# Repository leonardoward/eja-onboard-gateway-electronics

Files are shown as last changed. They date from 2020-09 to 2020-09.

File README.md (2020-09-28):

# EJA Onboard Gateway - Electronic Design

EJA Onboard Gateway - Electronic Design - [2020 Hackaday Dream Team Challenge for Conservation X Labs](https://hackaday.io/project/173457-2020-hdp-dream-team-conservation-x-labs)

Onboard Gateway is a 134.11 mm x 62.48 mm PCB that integrates the 3 main components (ESP32, LoRa and USB LiIon/LiPoly charger)

This repository contains the KiCad design for the PCB of the Onboard Gateway. It also contains the 3D models used to visualize the design in the KiCad 3D viewer.

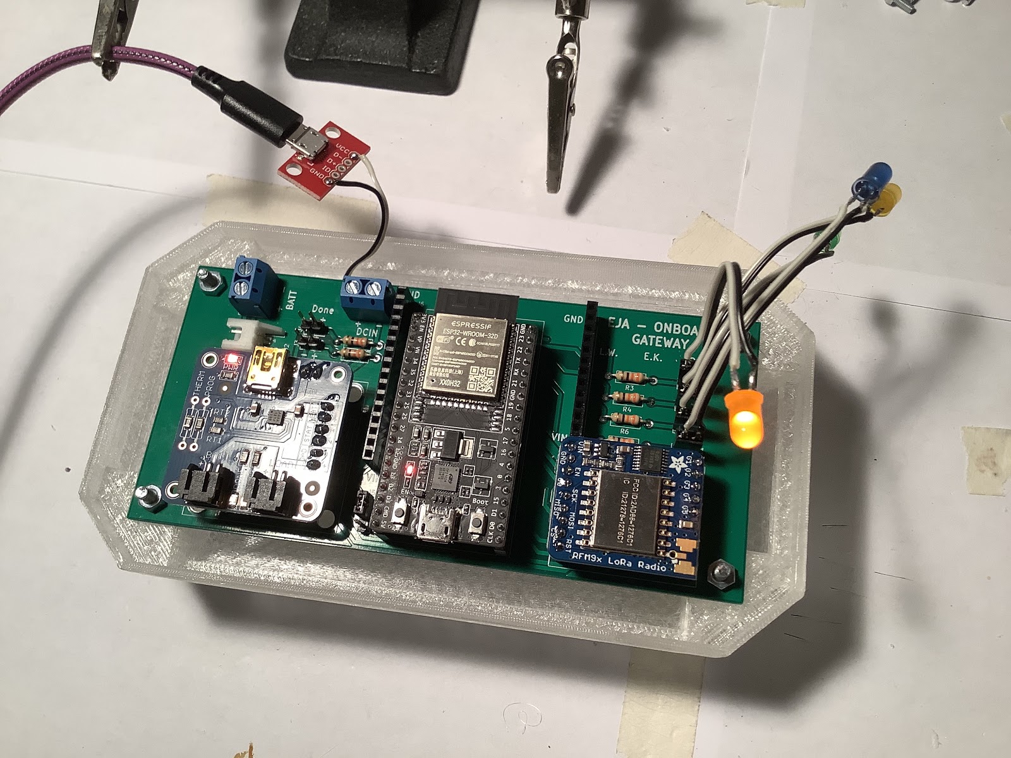
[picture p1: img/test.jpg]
Onboard Gateway


## Main Components ##

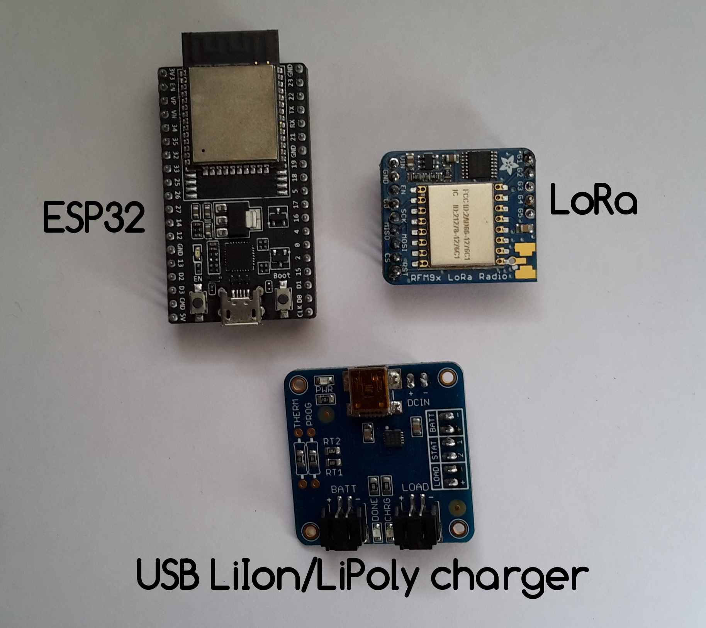
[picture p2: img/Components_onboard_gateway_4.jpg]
Components


Sources:

- [ESP32-DEVKITC-32D](https://www.digikey.com/product-detail/es/espressif-systems/ESP32-DEVKITC-32D/1965-1000-ND/9356990)
- [RFM95W LoRa Radio](https://www.digikey.com/product-detail/es/adafruit-industries-llc/3072/1528-1667-ND/6005357)
- [USB LiIon/LiPoly charger](https://www.adafruit.com/product/259)

## Schematic ##

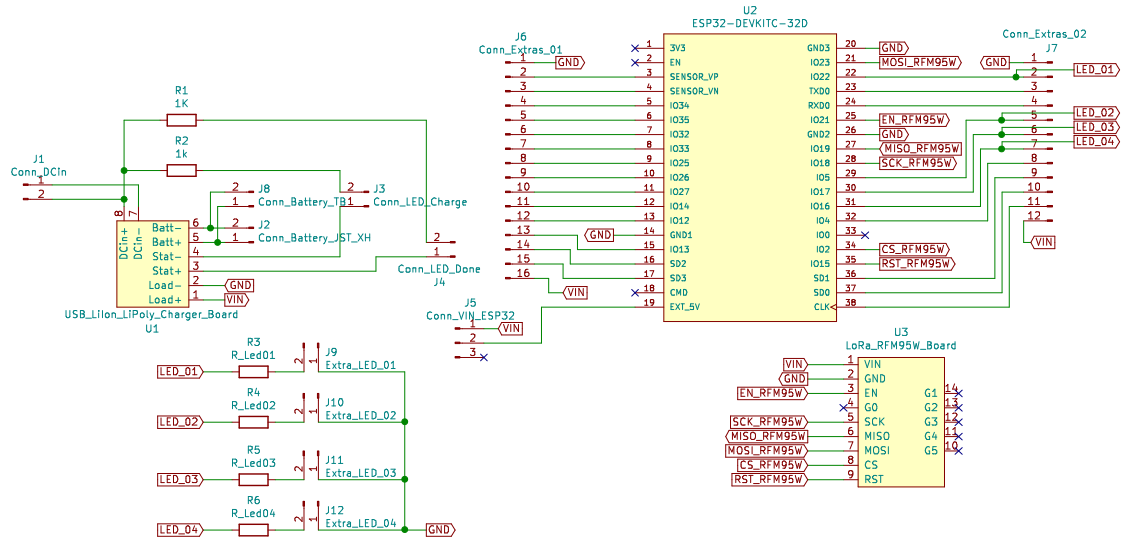
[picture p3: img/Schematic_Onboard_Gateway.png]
Schematic


[For a detailed explanation of the schematic visit the following log.](https://hackaday.io/project/173457/log/181839-onboard-gateway-v10-schematic-and-pcb-design)

## PCB Layout ##

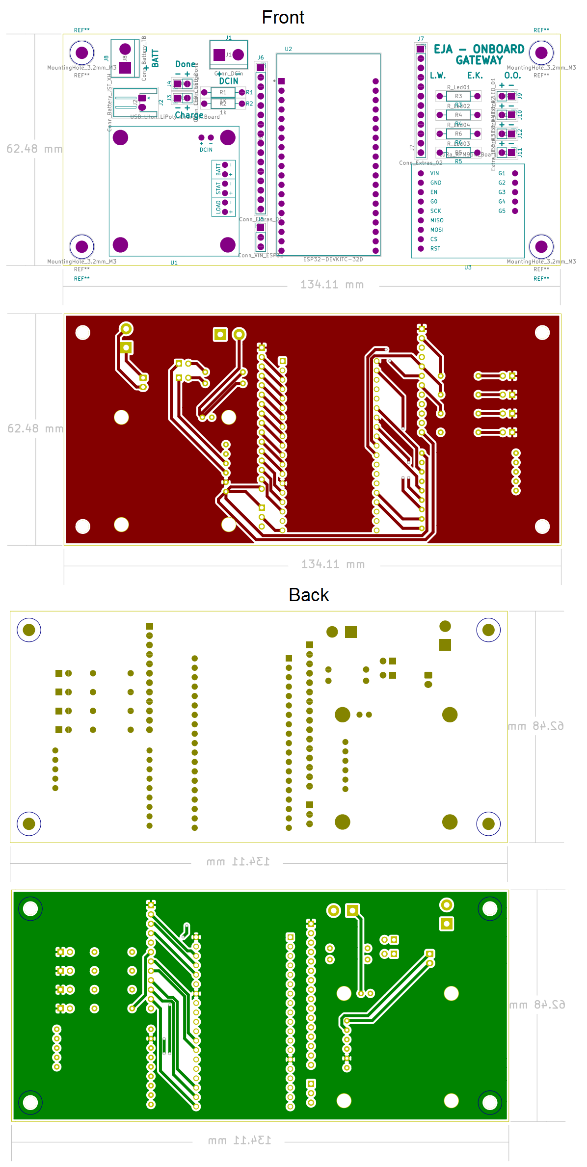
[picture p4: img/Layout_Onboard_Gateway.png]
PCB Layout


## Assembly ##

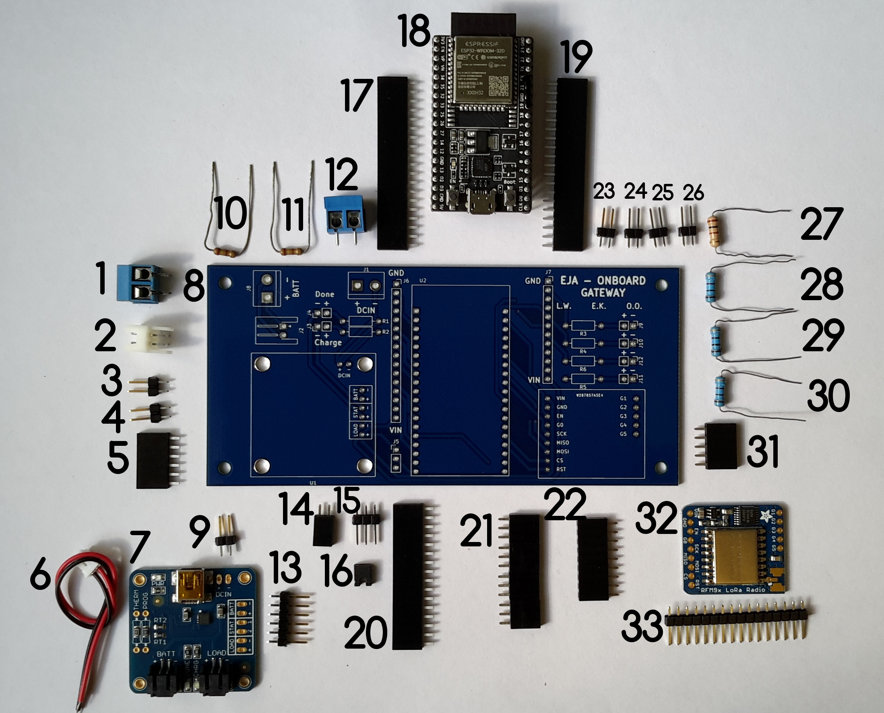
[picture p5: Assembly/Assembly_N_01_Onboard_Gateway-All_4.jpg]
Assembly Guide


Components List:

1. [TERM BLK 2P SIDE ENT 5.08MM PCB](https://www.digikey.com/product-detail/es/on-shore-technology-inc/OSTTC022162/ED2609-ND/614558)
2. [CONN HEADER R/A 2POS 2.5MM](https://www.digikey.com/product-detail/es/jst-sales-america-inc/S2B-XH-A-1-LF-SN/455-4226-ND/9961922)
3. [CONN HEADER VERT 2POS 2.54MM](https://www.digikey.com/product-detail/es/3m/2340-6111TG/3M11928-ND/1237275)
4. [CONN HEADER VERT 2POS 2.54MM](https://www.digikey.com/product-detail/es/3m/2340-6111TG/3M11928-ND/1237275)
5. [CONN HDR 6POS 0.1 TIN PCB](https://www.digikey.com/product-detail/es/sullins-connector-solutions/PPTC061LFBN-RC/S7004-ND/810145)
6. 2POS JST cable (included in the [USB LiIon/LiPoly charger](https://www.adafruit.com/product/259))
7. [USB LiIon/LiPoly charger](https://www.adafruit.com/product/259)
8. Onboard Gateway V1.0
9. [CONN HEADER VERT 2POS 2.54MM](https://www.digikey.com/product-detail/es/3m/2340-6111TG/3M11928-ND/1237275)
10. [RES 249 OHM 1/4W 1% AXIAL](https://www.digikey.com/product-detail/en/stackpole-electronics-inc/RNF14FTD249R/RNF14FTD249RCT-ND/1974990)
11. [RES 249 OHM 1/4W 1% AXIAL](https://www.digikey.com/product-detail/en/stackpole-electronics-inc/RNF14FTD249R/RNF14FTD249RCT-ND/1974990)
12. [TERM BLK 2P SIDE ENT 5.08MM PCB](https://www.digikey.com/product-detail/es/on-shore-technology-inc/OSTTC022162/ED2609-ND/614558)
13. [CONN HEADER VERT 6POS 2.54MM](https://www.digikey.com/product-detail/es/3m/2340-6111TG/3M11928-ND/1237275)
14. [CONN HDR 2POS 0.1 GOLD PCB](https://www.digikey.com/product-detail/es/sullins-connector-solutions/PPPC021LFBN-RC/S7035-ND/810174)
15. [CONN HEADER VERT 3POS 2.54MM](https://www.digikey.com/product-detail/es/3m/2340-6111TG/3M11928-ND/1237275)
16. [CONN JUMPER SHORTING .100" GOLD](https://www.digikey.com/product-detail/es/sullins-connector-solutions/QPC02SXGN-RC/S9337-ND/2618262)
17. [CONN HDR 19POS 0.1 TIN PCB](https://www.digikey.com/product-detail/es/sullins-connector-solutions/PPTC191LFBN-RC/S7017-ND/810157)
18. [ESP32-DEVKITC-32D](https://www.digikey.com/product-detail/es/espressif-systems/ESP32-DEVKITC-32D/1965-1000-ND/9356990)
19. [CONN HDR 19POS 0.1 TIN PCB](https://www.digikey.com/product-detail/es/sullins-connector-solutions/PPTC191LFBN-RC/S7017-ND/810157)
20. [CONN HDR 16POS 0.1 TIN PCB](https://www.digikey.com/product-detail/es/sullins-connector-solutions/PPTC161LFBN-RC/S7014-ND/810154)
21. [CONN HDR 12POS 0.1 TIN PCB](https://www.digikey.com/product-detail/es/sullins-connector-solutions/PPTC121LFBN-RC/S6100-ND/807231) (I used 2 [CONN HDR 6POS 0.1 TIN PCB](https://www.digikey.com/product-detail/es/sullins-connector-solutions/PPTC061LFBN-RC/S7004-ND/810145) in the image)
22. [CONN HDR 9POS 0.1 GOLD PCB](https://www.digikey.com/product-detail/es/sullins-connector-solutions/PPPC091LFBN-RC/S7042-ND/810181)
23. [CONN HEADER VERT 2POS 2.54MM](https://www.digikey.com/product-detail/es/3m/2340-6111TG/3M11928-ND/1237275)
24. [CONN HEADER VERT 2POS 2.54MM](https://www.digikey.com/product-detail/es/3m/2340-6111TG/3M11928-ND/1237275)
25. [CONN HEADER VERT 2POS 2.54MM](https://www.digikey.com/product-detail/es/3m/2340-6111TG/3M11928-ND/1237275)
26. [CONN HEADER VERT 2POS 2.54MM](https://www.digikey.com/product-detail/es/3m/2340-6111TG/3M11928-ND/1237275)
27. [RES 100 OHM 3W 5% AXIAL](https://www.digikey.com/product-detail/en/vishay-beyschlag-draloric-bc-components/AC03000001000JAC00/PPC3W100CT-ND/596604)
28. [RES 100 OHM 3W 5% AXIAL](https://www.digikey.com/product-detail/en/vishay-beyschlag-draloric-bc-components/AC03000001000JAC00/PPC3W100CT-ND/596604)
29. [RES 100 OHM 3W 5% AXIAL](https://www.digikey.com/product-detail/en/vishay-beyschlag-draloric-bc-components/AC03000001000JAC00/PPC3W100CT-ND/596604)
30. [RES 100 OHM 3W 5% AXIAL](https://www.digikey.com/product-detail/en/vishay-beyschlag-draloric-bc-components/AC03000001000JAC00/PPC3W100CT-ND/596604)
31. [CONN HDR 5POS 0.1 GOLD PCB](https://www.digikey.com/product-detail/es/sullins-connector-solutions/PPTC051LFBN-RC/S6103-ND/807239)
32. [RFM95W LoRa Radio](https://www.digikey.com/product-detail/es/adafruit-industries-llc/3072/1528-1667-ND/6005357)
33. CONN HEADER VERT 16POS 2.54MM (included in [RFM95W LoRa Radio](https://www.digikey.com/product-detail/es/adafruit-industries-llc/3072/1528-1667-ND/6005357))

[For a detailed Bill of Materials visit the following log.](https://hackaday.io/project/173457/log/183759-onboard-gateway-v10-bill-of-materials)

[For a detailed explanation about the soldering and assembly procedure visit the following log.](https://hackaday.io/project/173457/log/183665-onboard-gateway-v10-assembly)

## Wiring Diagrams ##

The following diagram presents the physical connections of the different boards and components of the Onboard Gateway, that includes:

- 3.7V 1 Cell Battery
- Leds (Charge, Done and 4 Miscellaneous)
- PCB Board for the Onboard Gateway V1.0
- 5V Charger (only used to charge the battery)
- Micro USB Breakout Board
- Switch

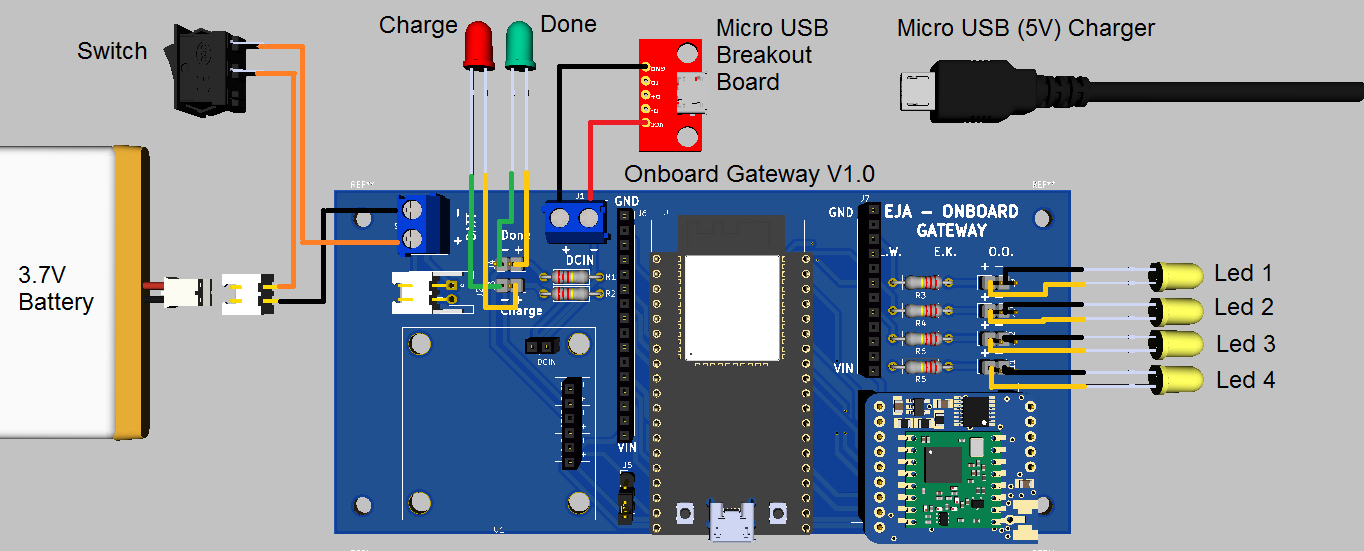
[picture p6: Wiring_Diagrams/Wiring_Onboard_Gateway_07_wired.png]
Wiring Diagrams


[For more information about the wiring diagrams and the project visit the following log.](https://hackaday.io/project/173457-2020-hdp-dream-team-conservation-x-labs/log/182586-onboard-gateway-v10-wiring-diagram)

## Future improvements ##

[For more information about the recommended future improvements for the electronic design visit the following log.](https://hackaday.io/project/173457/log/183807-future-improvements-pcb-design)

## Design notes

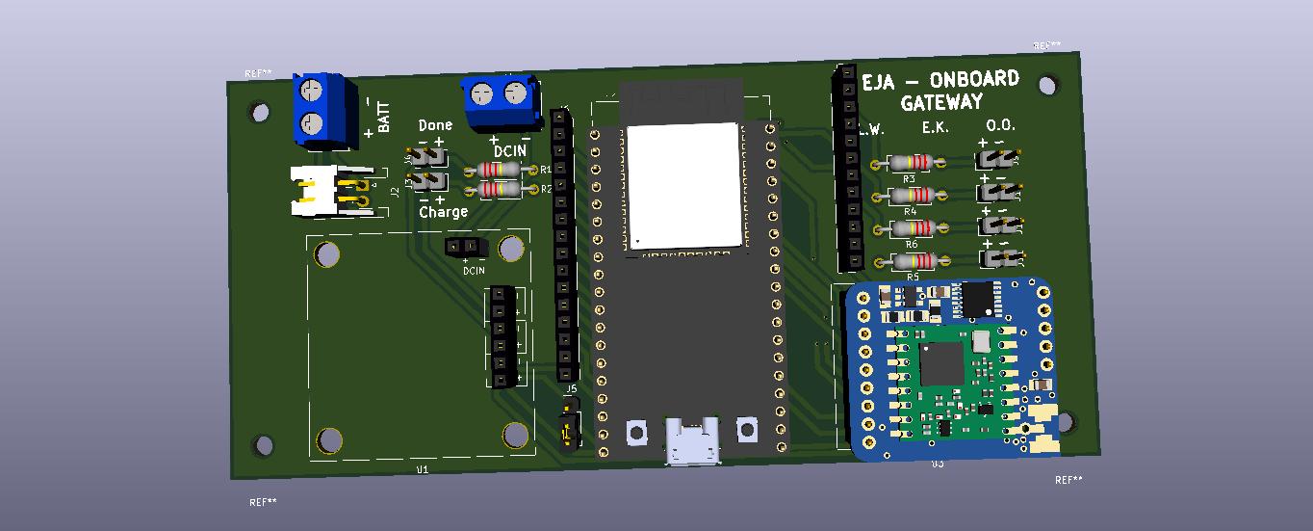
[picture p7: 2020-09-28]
img/Onboard_Gateway_V1.0_01.jpg

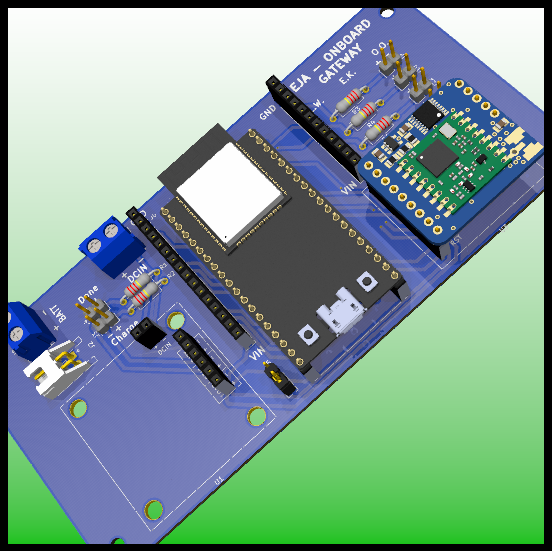
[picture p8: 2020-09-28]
img/Onboard Gateway V1.0 02.png

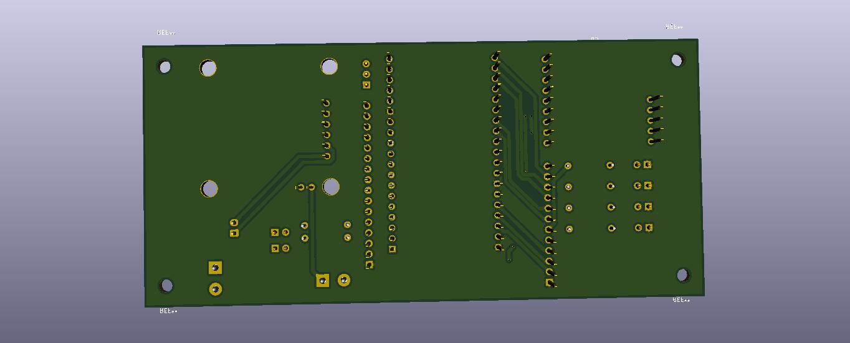
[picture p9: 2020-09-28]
img/Onboard_Gateway_V1.0_02.jpg

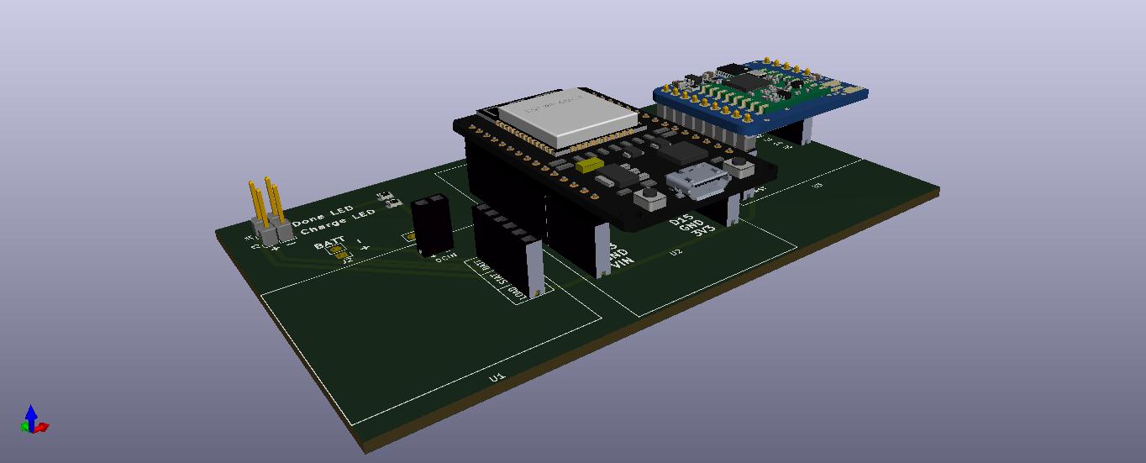
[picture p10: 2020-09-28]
img/Onboard_Gateway_02.jpg

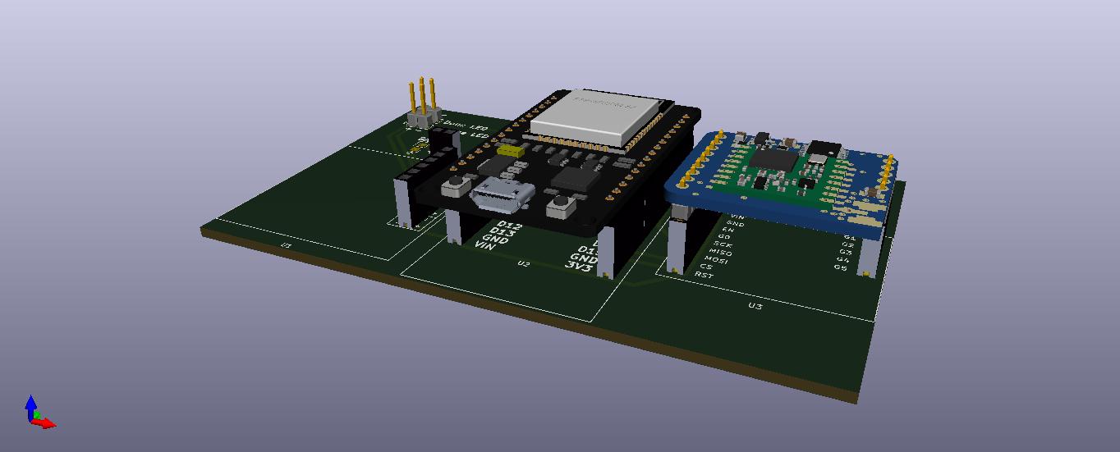
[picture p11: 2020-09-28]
img/Onboard_Gateway_03.jpg

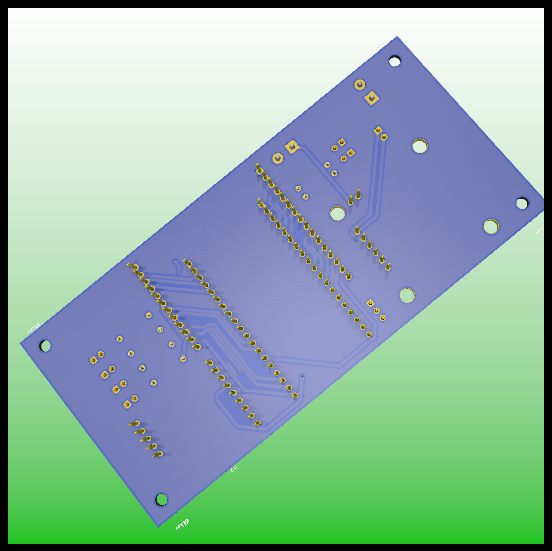
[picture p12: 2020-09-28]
img/Onboard Gateway V1.0 06.png

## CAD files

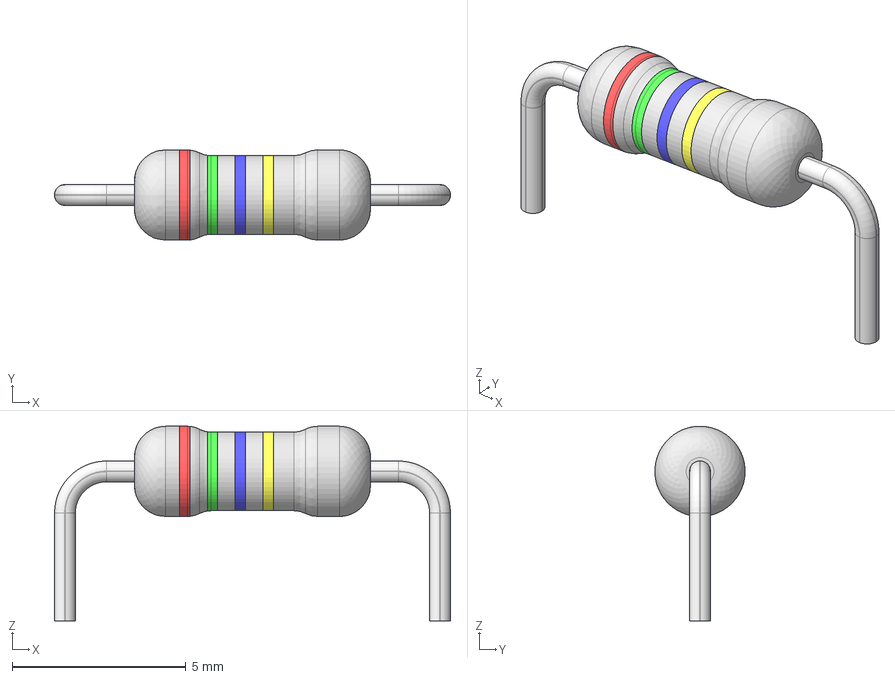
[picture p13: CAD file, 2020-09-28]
3D/axial_resistor_L6.8_D2.6_PinD0.6_Pitch10.8_gray.step
11.4 x 2.60 x 5.60 mm

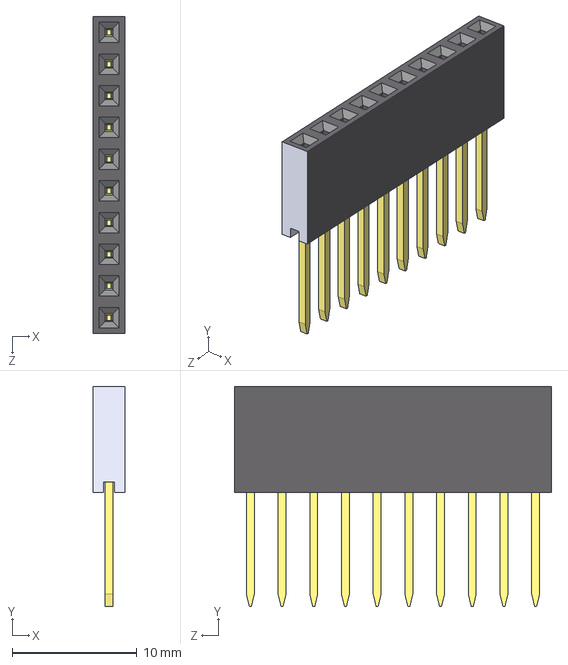
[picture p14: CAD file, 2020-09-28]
3D/Female Header 1x10.STEP
2.54 x 17.6 x 25.4 mm

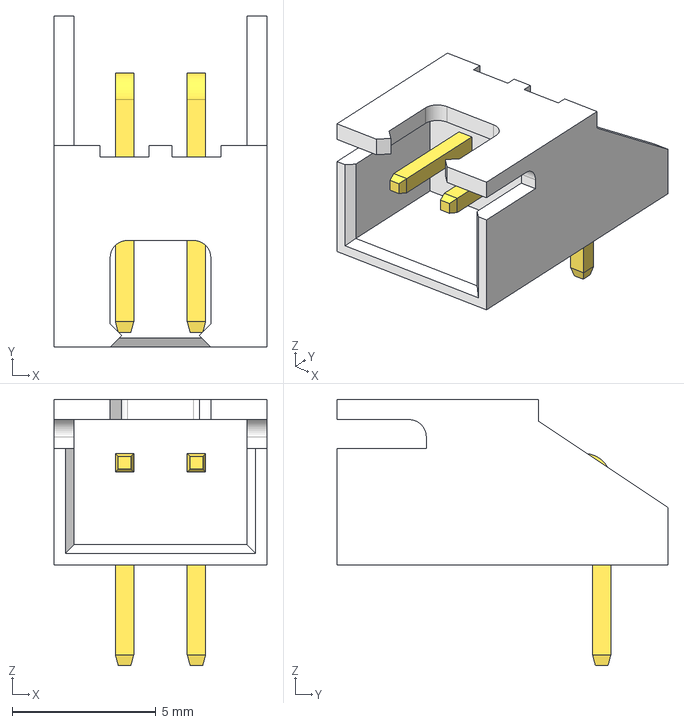
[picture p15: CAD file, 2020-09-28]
3D/S2B-XH-A.step
7.40 x 11.5 x 9.25 mm

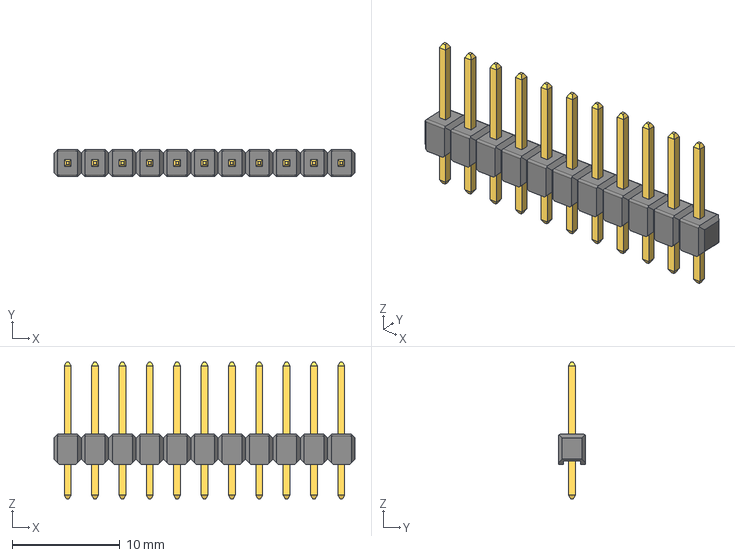
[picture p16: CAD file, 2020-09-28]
3D/Pin Header 1x11 TH Pitch 2.54mm.stp
27.9 x 2.54 x 12.7 mm

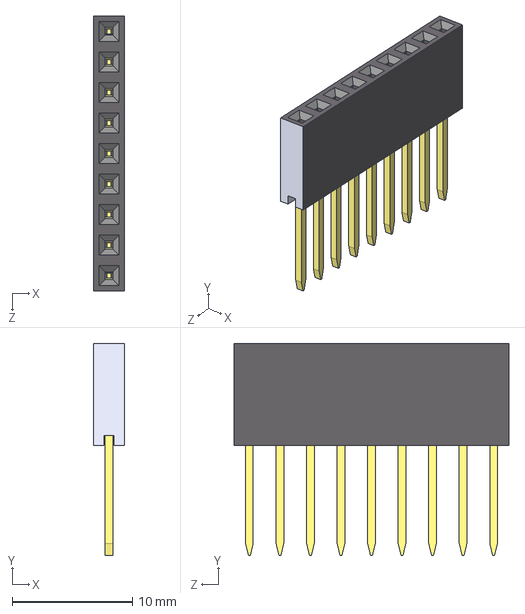
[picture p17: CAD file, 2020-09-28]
3D/Female Header 1x9.STEP
2.54 x 17.6 x 22.9 mm

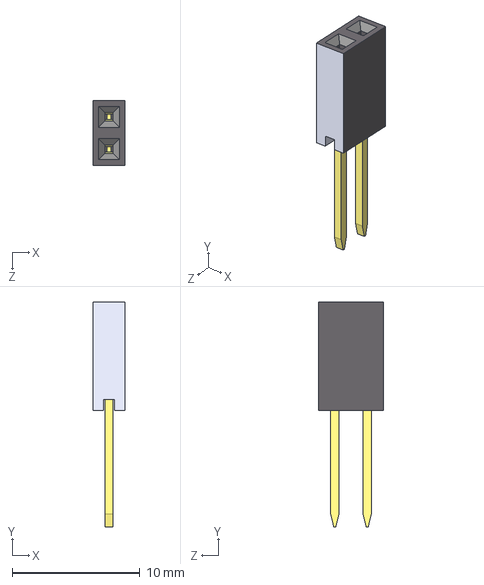
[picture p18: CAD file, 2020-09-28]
3D/Female Header 1x2.STEP
2.54 x 17.6 x 5.08 mm

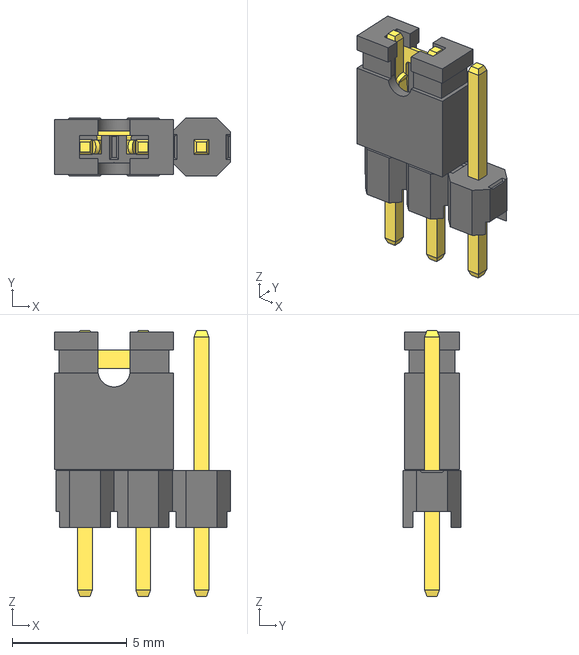
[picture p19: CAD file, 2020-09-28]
3D/Jumper3.step
7.68 x 2.54 x 11.6 mm

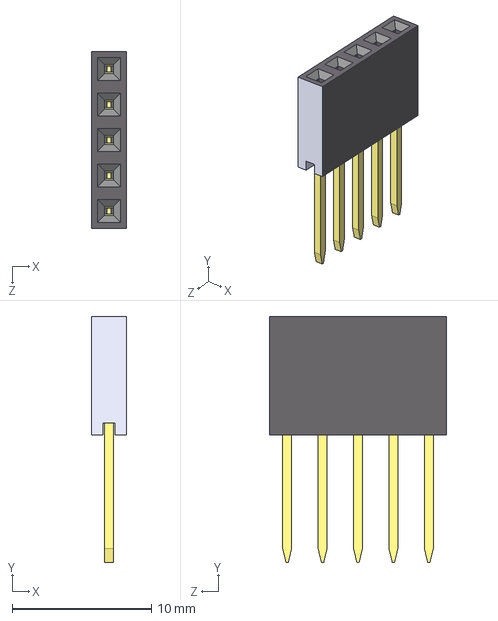
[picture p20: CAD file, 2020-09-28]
3D/Female Header 1x5.STEP
2.54 x 17.6 x 12.7 mm

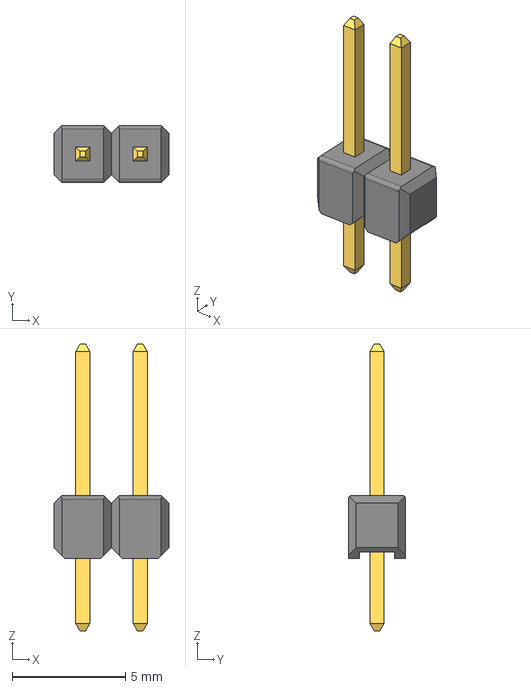
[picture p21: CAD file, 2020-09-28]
3D/Pin Header 1x2 TH Pitch 2.54mm.stp
5.08 x 2.54 x 12.7 mm

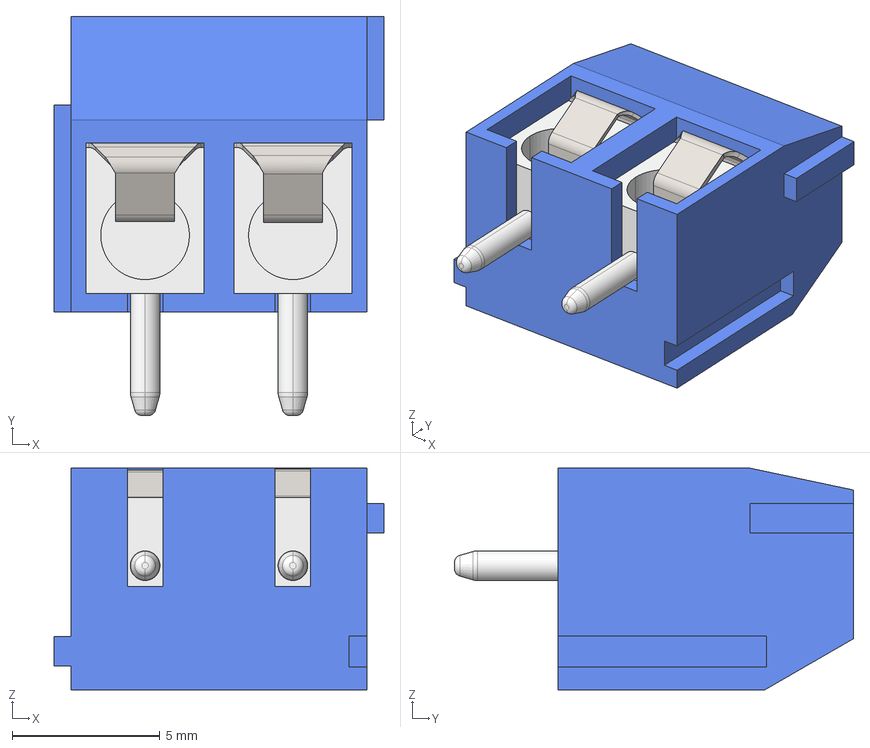
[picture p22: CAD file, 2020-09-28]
3D/TE_1776244-2.STEP
11.2 x 13.5 x 7.50 mm

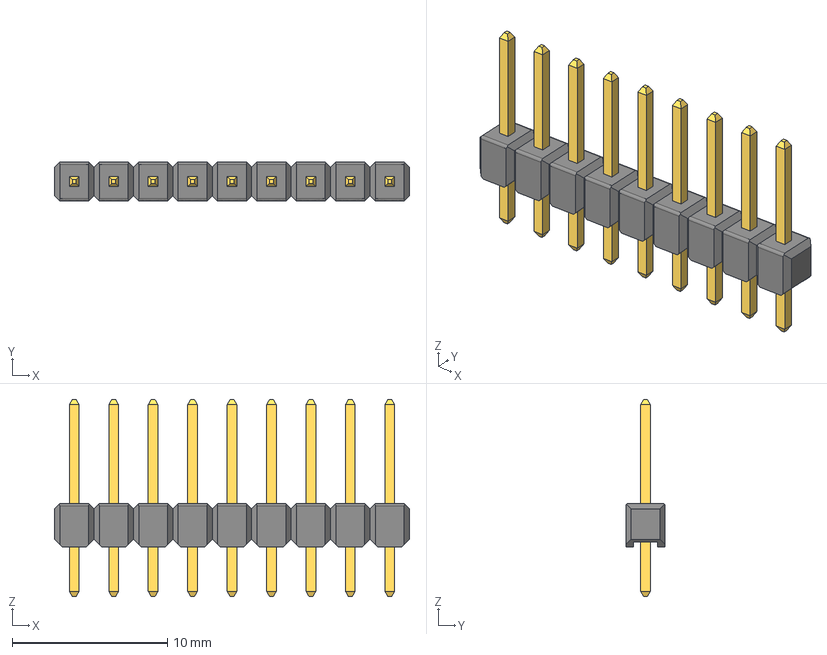
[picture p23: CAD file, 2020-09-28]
3D/Pin Header 1x9 TH Pitch 2.54mm.stp
22.9 x 2.54 x 12.7 mm

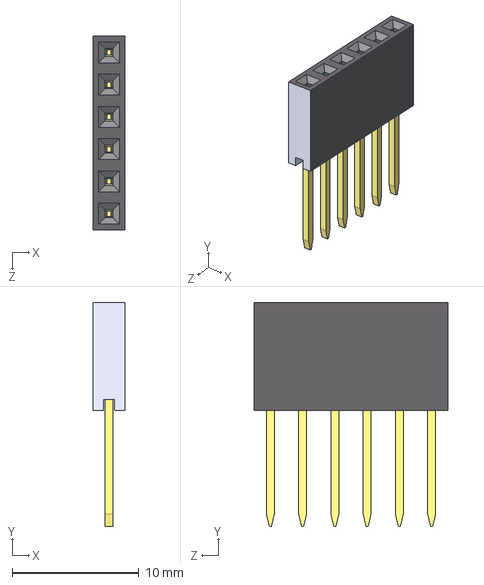
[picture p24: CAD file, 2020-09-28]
3D/Female Header 1x6.STEP
2.54 x 17.6 x 15.2 mm

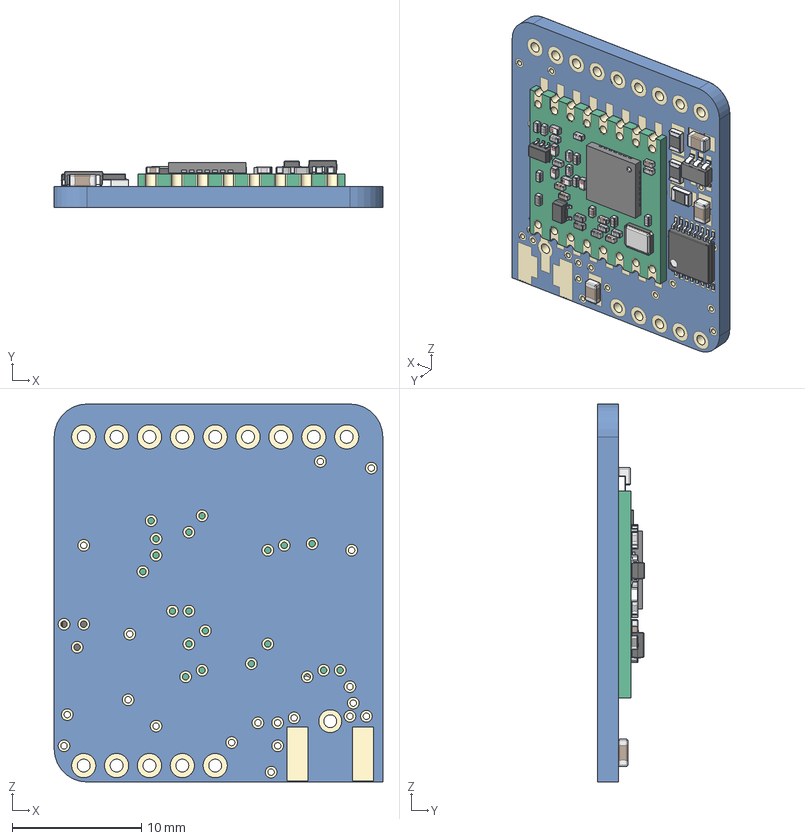
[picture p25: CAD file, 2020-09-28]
3D/RFM95W v5.step
25.4 x 3.63 x 29.2 mm
QFN 28 v2
SMD Crystal v1
CAP 0403 v1 x 8
CAP Ceramic 0403 v1 x 8
Res 0403 v1 x 4
CAP ML 0403 v1 x 5
SOT-323 v1
Inductor SMD 0403 v1 x 5
SOT-363 v1
SOT23-5
CAP 0805 T095 x 2
CAP 0805 T075
TSSOP16
RES 0805 x 3

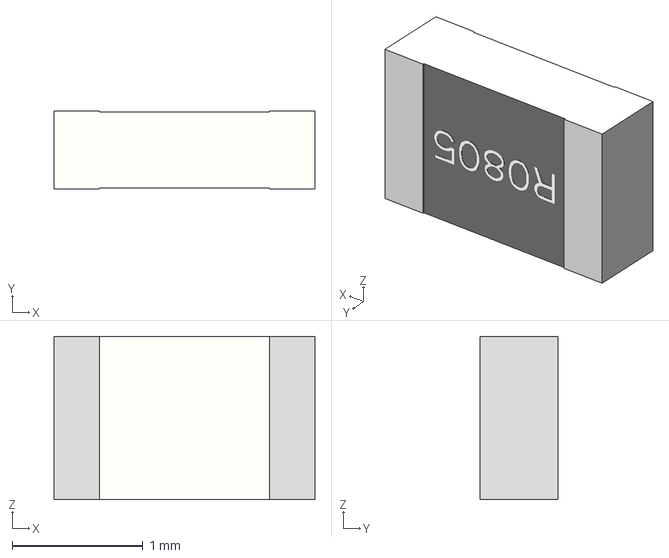
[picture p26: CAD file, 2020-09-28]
3D/rsmd-0805_l2_w1-25_h0-6.stp
2.00 x 0.6 x 1.25 mm

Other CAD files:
3D/Pin Header 1x12 TH Pitch 2.54mm.stp
3D/Pin Header 1x5 TH Pitch 2.54mm.stp

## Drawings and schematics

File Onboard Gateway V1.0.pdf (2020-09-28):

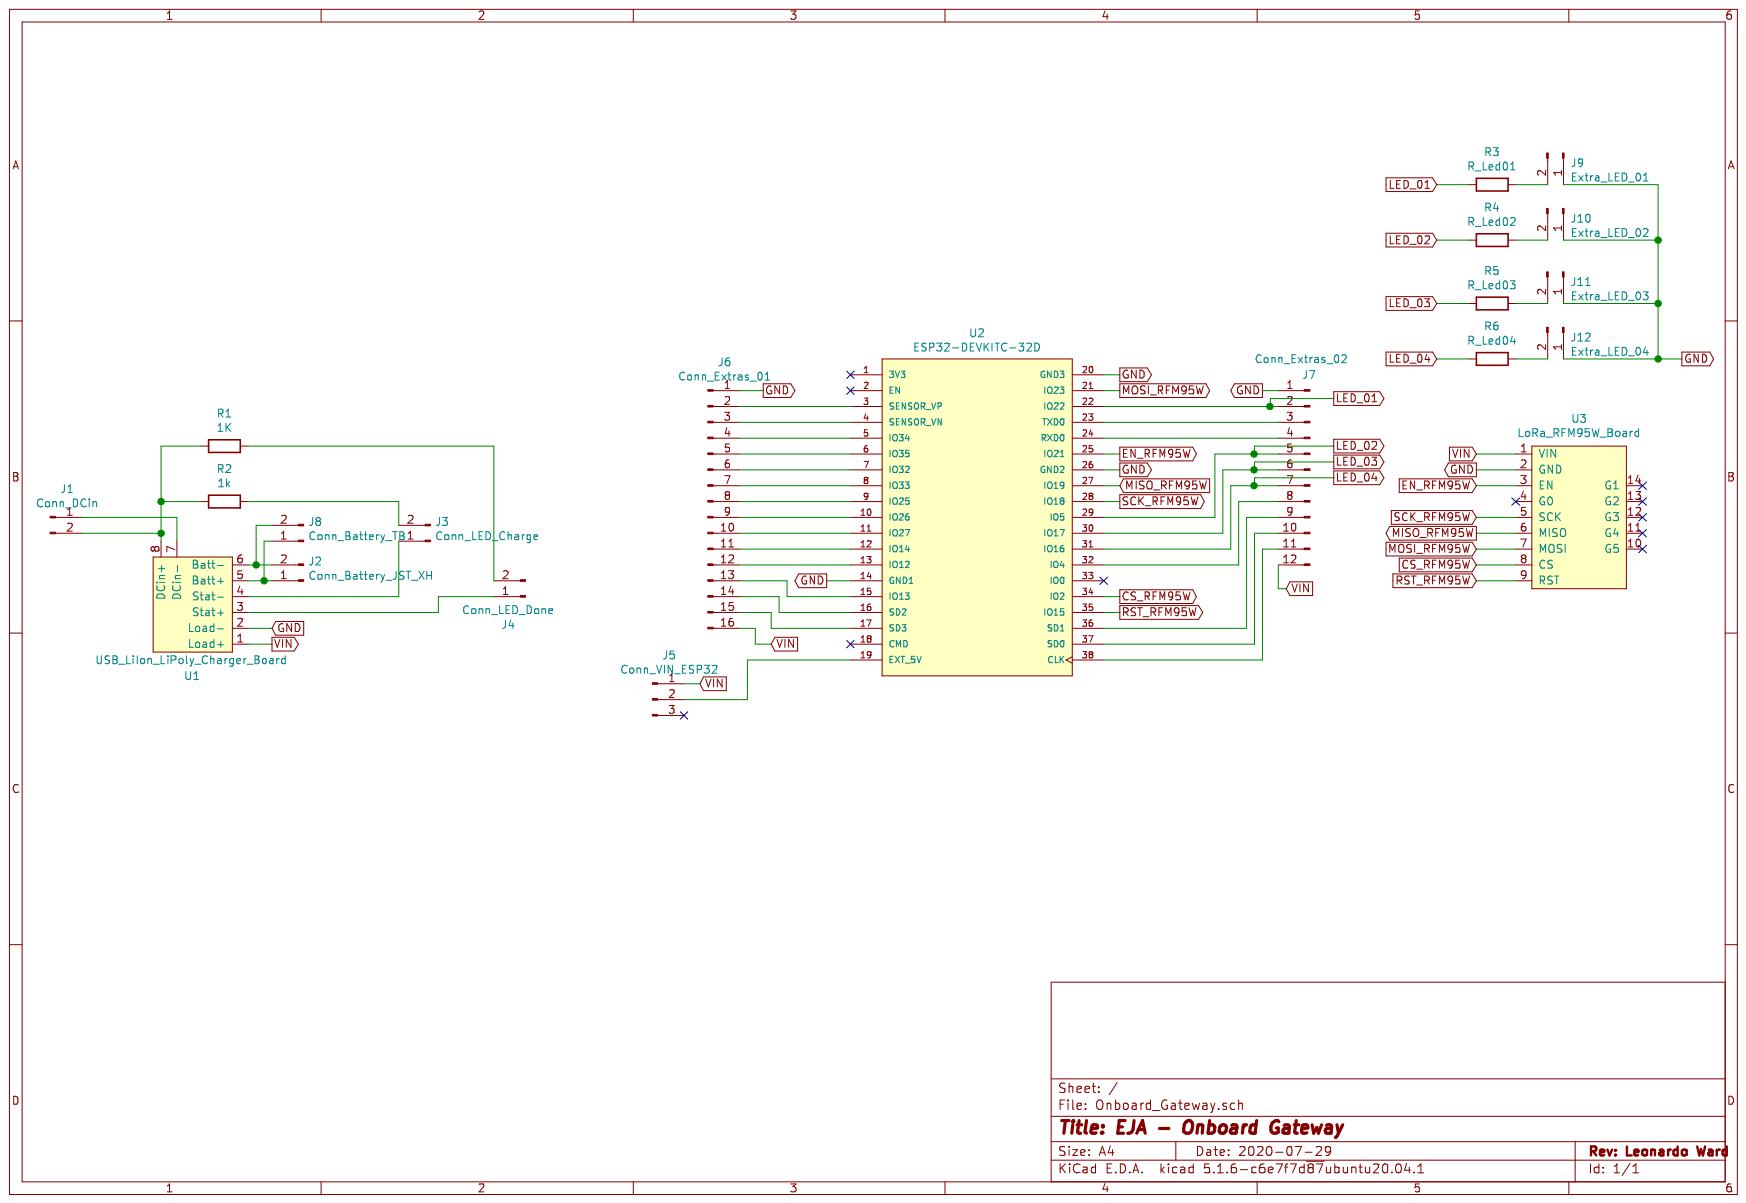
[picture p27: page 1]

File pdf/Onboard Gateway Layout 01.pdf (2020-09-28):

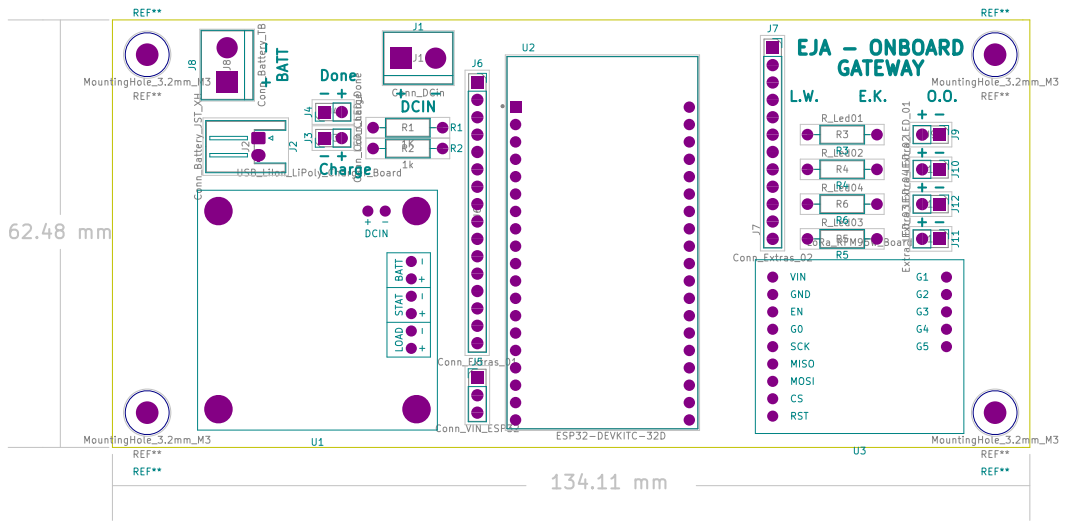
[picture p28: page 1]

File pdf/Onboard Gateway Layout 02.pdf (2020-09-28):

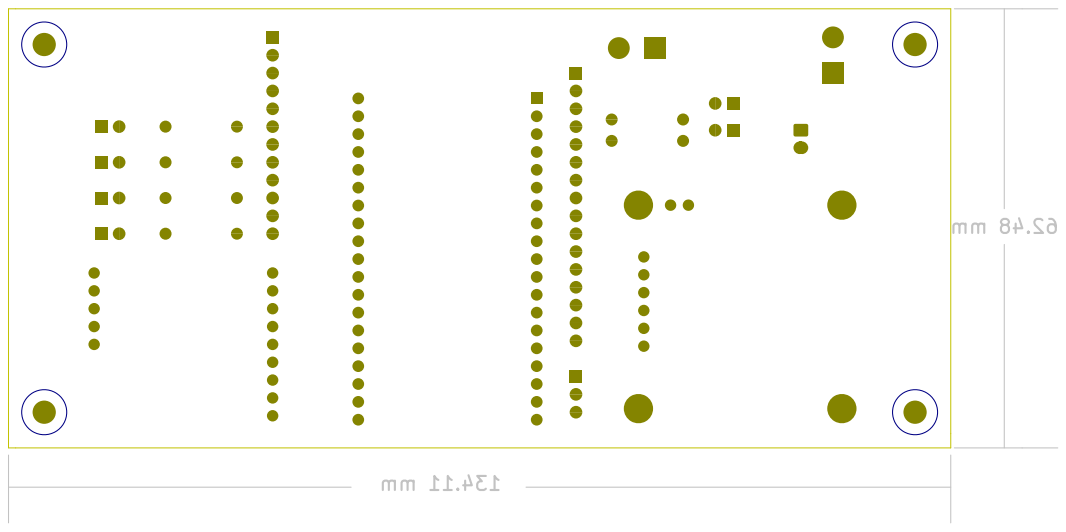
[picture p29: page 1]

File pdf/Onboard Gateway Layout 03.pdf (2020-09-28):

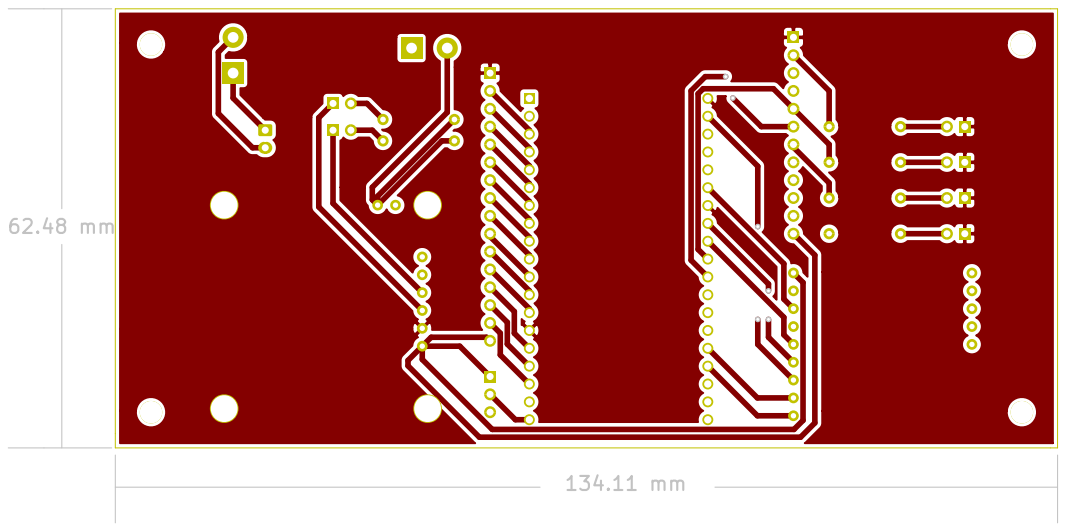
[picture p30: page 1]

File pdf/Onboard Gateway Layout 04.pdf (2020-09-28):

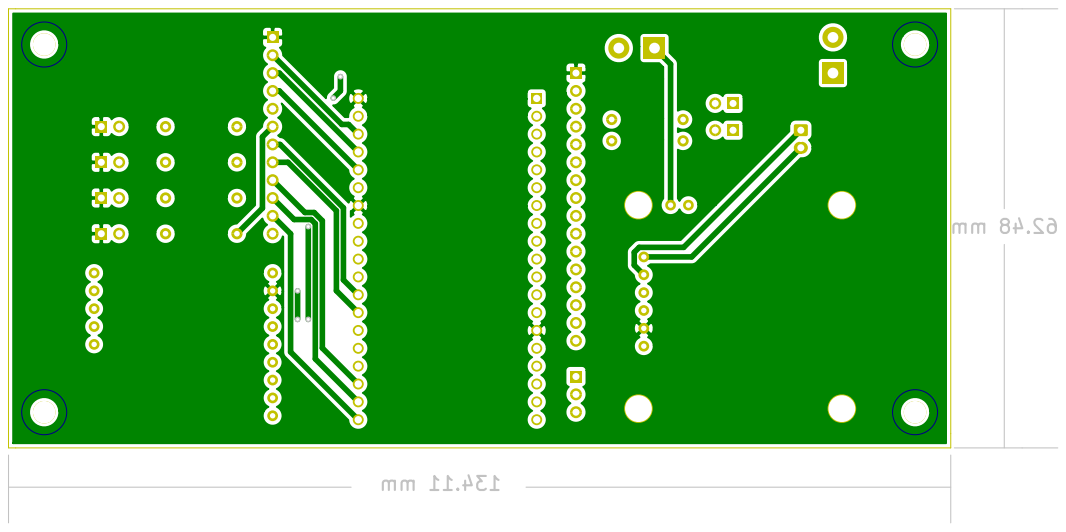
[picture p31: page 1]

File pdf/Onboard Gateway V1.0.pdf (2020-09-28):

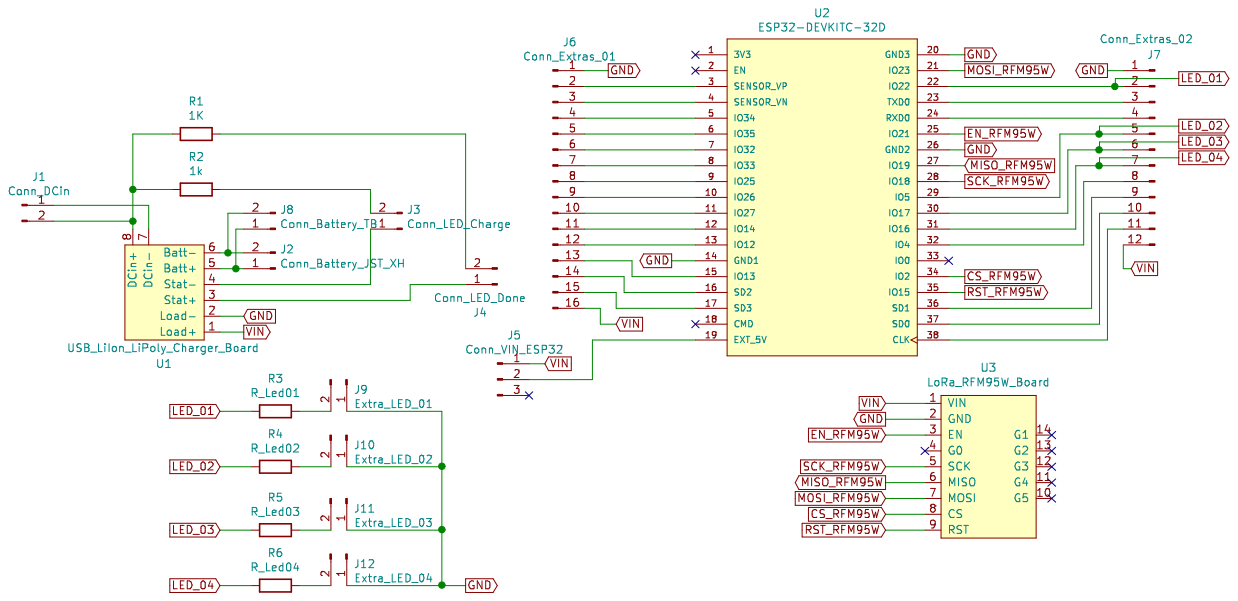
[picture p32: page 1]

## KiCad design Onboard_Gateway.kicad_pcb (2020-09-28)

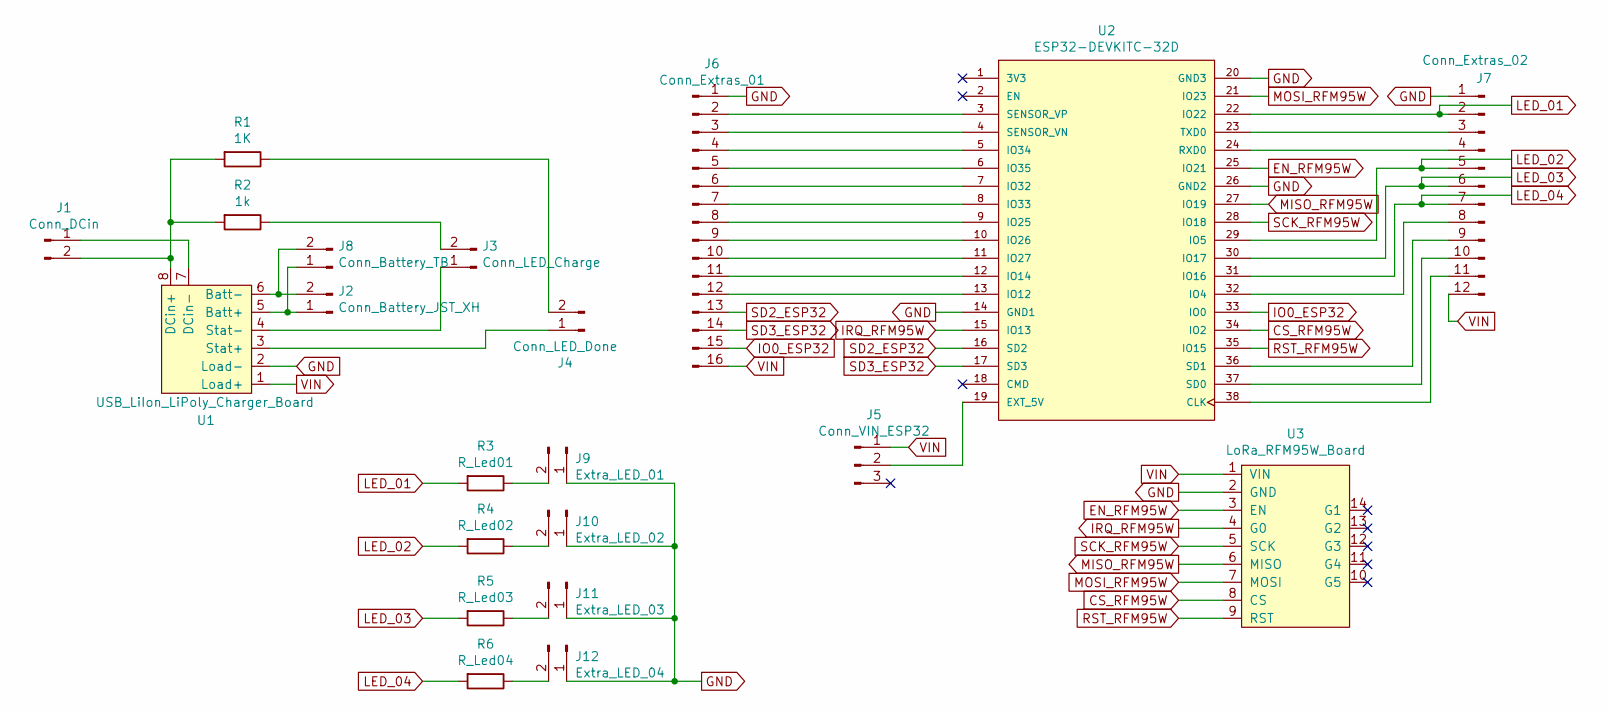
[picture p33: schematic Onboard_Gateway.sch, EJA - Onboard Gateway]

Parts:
J1: Conn_DCin; TerminalBlock_bornier-2_P5.08mm
J2: Conn_Battery_JST_XH; JST_XH_S2B-XH-A-1_1x02_P2.50mm_Horizontal
J3: Conn_LED_Charge; PinHeader_1x02_P2.54mm_Vertical
J4: Conn_LED_Done; PinHeader_1x02_P2.54mm_Vertical
J5: Conn_VIN_ESP32; PinHeader_1x03_P2.54mm_Vertical
J6: Conn_Extras_01; PinSocket_1x16_P2.54mm_Vertical
J7: Conn_Extras_02; PinSocket_1x12_P2.54mm_Vertical
J8: Conn_Battery_TB; TerminalBlock_bornier-2_P5.08mm
J9: Extra_LED_01; PinHeader_1x02_P2.54mm_Vertical
J10: Extra_LED_02; PinHeader_1x02_P2.54mm_Vertical
J11: Extra_LED_03; PinHeader_1x02_P2.54mm_Vertical
J12: Extra_LED_04; PinHeader_1x02_P2.54mm_Vertical
R1: 1K; R_Axial_DIN0207_L6.3mm_D2.5mm_P10.16mm_Horizontal
R2: 1k; R_Axial_DIN0207_L6.3mm_D2.5mm_P10.16mm_Horizontal
R3: R_Led01; R_Axial_DIN0207_L6.3mm_D2.5mm_P10.16mm_Horizontal
R4: R_Led02; R_Axial_DIN0207_L6.3mm_D2.5mm_P10.16mm_Horizontal
R5: R_Led03; R_Axial_DIN0207_L6.3mm_D2.5mm_P10.16mm_Horizontal
R6: R_Led04; R_Axial_DIN0207_L6.3mm_D2.5mm_P10.16mm_Horizontal
U1: USB_LiIon_LiPoly_Charger_Board
U2: ESP32-DEVKITC-32D; MODULE_ESP32-DEVKITC-32D
U3: LoRa_RFM95W_Board; RFM95W-Board

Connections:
CS_RFM95W: U2.34 (IO2), U3.8 (CS)
EN_RFM95W: U2.25 (IO21), U3.3 (EN)
GND: J6.1, J7.1, J9.1, J10.1, J11.1, J12.1, U1.2 (Load-), U2.14 (GND1), U2.20 (GND3), U2.26 (GND2), U3.2 (GND)
IO0_ESP32: J6.15, U2.33 (IO0)
IRQ_RFM95W: U2.15 (IO13), U3.4 (G0)
LED_01: J7.2, R3.2, U2.22 (IO22)
LED_02: J7.5, R4.2, U2.29 (IO5)
LED_03: J7.6, R5.2, U2.30 (IO17)
LED_04: J7.7, R6.2, U2.31 (IO16)
MISO_RFM95W: U2.27 (IO19), U3.6 (MISO)
MOSI_RFM95W: U2.21 (IO23), U3.7 (MOSI)
unnamed: J1.1, U1.7 (DCin-)
unnamed: J1.2, R1.2, R2.2, U1.8 (DCin+)
unnamed: J2.1, J8.1, U1.5 (Batt+)
unnamed: J2.2, J8.2, U1.6 (Batt-)
unnamed: J3.1, U1.4 (Stat-)
unnamed: J3.2, R2.1
unnamed: J4.1, U1.3 (Stat+)
unnamed: J4.2, R1.1
unnamed: J5.2, U2.19 (EXT_5V)
unnamed: J6.2, U2.3 (SENSOR_VP)
unnamed: J6.3, U2.4 (SENSOR_VN)
unnamed: J6.4, U2.5 (IO34)
unnamed: J6.5, U2.6 (IO35)
unnamed: J6.6, U2.7 (IO32)
unnamed: J6.7, U2.8 (IO33)
unnamed: J6.8, U2.9 (IO25)
unnamed: J6.9, U2.10 (IO26)
unnamed: J6.10, U2.11 (IO27)
unnamed: J6.11, U2.12 (IO14)
unnamed: J6.12, U2.13 (IO12)
unnamed: J7.3, U2.23 (TXD0)
unnamed: J7.4, U2.24 (RXD0)
unnamed: J7.8, U2.32 (IO4)
unnamed: J7.9, U2.36 (SD1)
unnamed: J7.10, U2.37 (SD0)
unnamed: J7.11, U2.38 (CLK)
unnamed: J9.2, R3.1
unnamed: J10.2, R4.1
unnamed: J11.2, R5.1
unnamed: J12.2, R6.1
RST_RFM95W: U2.35 (IO15), U3.9 (RST)
SCK_RFM95W: U2.28 (IO18), U3.5 (SCK)
SD2_ESP32: J6.13, U2.16 (SD2)
SD3_ESP32: J6.14, U2.17 (SD3)
VIN: J5.1, J6.16, J7.12, U1.1 (Load+), U3.1 (VIN)

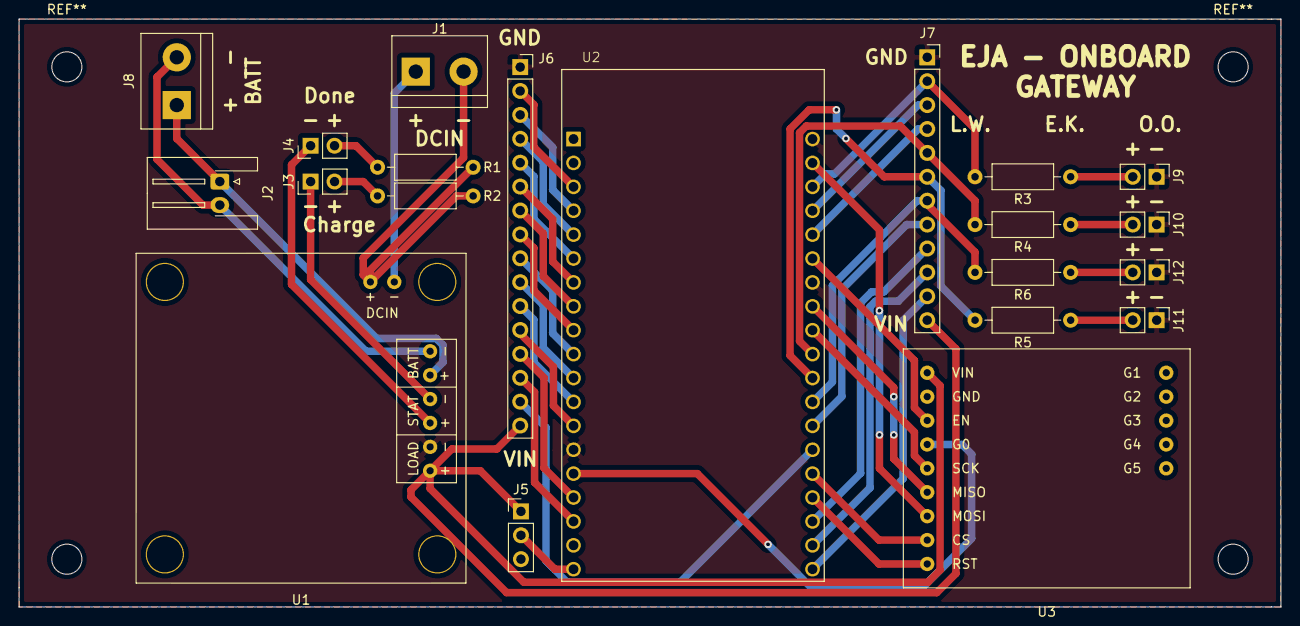
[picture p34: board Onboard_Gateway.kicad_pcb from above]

Board: 2 copper layers, 134.1 x 62.5 mm, 21 parts (0 on the bottom side), 46 nets.

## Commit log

2020-09-28 Added KiCad design
    [Female Header 1x10.STEP, Female Header 1x2.STEP, Female Header 1x5.STEP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]
2020-09-28 Added assembly guide and wiring diagrams
